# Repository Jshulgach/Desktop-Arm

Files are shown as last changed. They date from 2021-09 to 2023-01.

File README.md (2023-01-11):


# Desktop-Robotic-Arm
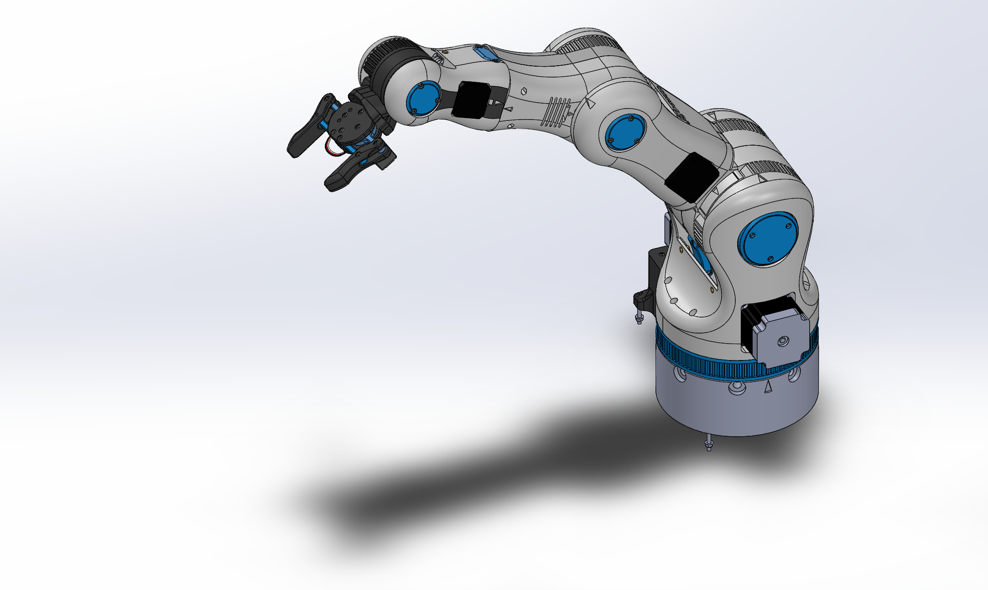
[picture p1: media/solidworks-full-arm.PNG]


The Desktop Robot Arm (better name TBD) is the complete package of a ROS2-based robot controller and the [Moveo](https://www.bcn3d.com/bcn3d-moveo-the-future-of-learning-robotic-arm/), a small-medium-sized fully 3D printable Open source 6 axis robotic arm. 

It is functionally and aesthetically similar to other amazing robot arms like the [KUKA KG Agilus](https://www.kuka.com/en-us/products/robotics-systems/industrial-robots/kr-agilus) or the [Fanuc LR Mate](https://www.fanucamerica.com/products/robots/series/lr-mate/lr-mate-200id) robotic arms in the robotics industry but is aimed for personal use, research, education and anyone interested in making their own robotic arm, at an affordable price! 

The main "selling points" of this arm that separate it from other existing DIY arms are:
+ Raspberry Pi 4 Model B - main processing unit for motion planning and listener routines
+ Arduino Mega microcontroller to interface with the robot systems
+ Runs on ROS2 (with Moveit2 for motion planning)
+ All 3D printable components (aside from nuts & bolts)
+ Less that $1,000 with the B.O.M
+ Capacity to integrate more features

# Where to start ? 
This Github repository contains Installation and Quick Start instructions for the Desktop Robot Arm project running ROS2 Humble off a Raspberry Pi 4, and contains folders for scripts, libraries, examples, and readme files. If you want to make the arm yourself, start with Hardware.

Table of Contents
---
+ [Hardware](#hardware)
+ [Raspberry PI 4 Installation](#rpi4-installation)
+ [Arduino Setup](#arduino-setup)
+ [Dance Demo](#demo)
+ [XBox Teleop](#xbox-teleop)
+ [Simulated Model](#simulated-model)
+ [Voice Control - Coming Soon!](#voice-control)
+ [Home Assistant Integration - Coming Soon!](#home-assistant-integration)
+ [HTC Vive Integration - coming Soon!](#htc-vive)
---

## Hardware:
<a name="hardware"/>

1. Building the arm
   + The full list of parts needed to assemble the arm can be found in the [B.O.M](tbd).

   + Instructables has a greate [step-by-step guide](https://www.instructables.com/Build-a-Giant-3D-Printed-Robot-Arm/) on 3D printing and assembling the arm pieces. 

2. Electrical wiring
   + A wiring diagram for the RAMPS 1.4 shield and Arduino Mega can be found in the [Electrical](tbd) folder.
   + A reference for the RAMPS 1.4 shield can be found on their [website](https://reprap.com/wiki/RAMPS_1.4) which shows the pin assignments. Please be sure to refer only to the 1.4 version of the shield.

---

## Raspberry Pi 4 Software Installation:
<a name="rpi4-installation"/>
These instructions were tested on Ubuntu 22.04.1 LTS running on a Raspberry Pi 4 64-bit 4Gb. If starting with a brand new Raspi and a blank microSD card, start with step 1 if you need to set up hardware.

1. Download the following software packages for flashing and writing to a new microSD card
   + [SD Memory Card Formatter](https://www.sdcard.org/downloads/formatter/)
   + [Raspberry Pi Imager](https://www.raspberrypi.com/software/)

2. Setting up Raspberry Pi 4
   + Follow the Imager instructions on writing the Ubuntu server image on Raspi 4. Please select Ubuntu 22.04 LTS. DO NOT install Ubuntu 22.10 LTS as the ROS2 humble debian packages aren't supported yet.
 
3. Install packages
   + Clone the Desktop Arm Github repository onto the specific `ros2_ws` folder which we create 
     ~~~
     mkdir -p ~/ros2_ws/src
     cd ~/ros2_ws/src
     git clone https://github.com/Jshulgach/Desktop-Arm.git
     ~~~

   + Run the `install.sh` bash script, which also includes installation steps for [ROS2 Humble](https://docs.ros.org/en/humble/Installation/Ubuntu-Development-Setup.html), [Moveit2](https://moveit.ros.org/install-moveit2/binary/), SSH, and other packages.
     ~~~
     cd Desktop-Arm
     chmod +x install.sh
     ./install.sh
     ~~~
4. DDNS Setup (Optional)
   + To allow access and remote control over the internet, we need to set up a Dynamic DNS. I've used the service [no-ip](https://www.noip.com) to create a free account and host a domain for the Raspberry Pi. [First create an account](https://www.noip.com/sign-up). More detailed instructions on setup are available on their [support page](https://www.noip.com/support/knowledgebase/installing-the-linux-dynamic-update-client-on-ubuntu/)
   + Download and install the no-ip software. You will be prompted to login with your No-IP account username and password. After logging into the DUC answer the questions to proceed. When asked how often you want the update to happen you can select the default number 30 (the interval is listed in minutes).
     ~~~
     mkdir ~/noip
     cd ~/noip
     wget https://www.noip.com/client/linux/noip-duc-linux.tar.gz
     tar vzxf noip-duc-linux.tar.gz
     cd noip-2.1.9-1
     sudo make
     sudo make install
     ~~~
   + Launch the client in the background and enable startup on boot
     ~~~
     sudo /usr/local/bin/noip2 -C
     systemctl enable noip2.service
     ~~~

## Arduino Setup:
<a name="arduino-setup"/>

An [Arduino Mega](https://diyi0t.com/arduino-mega-tutorial/) microcontroller is used to fit with the [RAMPS 1.4 Shield](https://reprap.org/wiki/RAMPS_1.4). Since the shield was designed to control a 3D printer or CNC machine with various stepper motor controllers and servos (along with limit switches and sensor readings), it was a great existing product to utilize. The primary microcontroller firmware needs to be [uploaded](https://docs.arduino.cc/software/ide-v2/tutorials/getting-started/ide-v2-uploading-a-sketch) onto the Arduino Mega, but it is RECOMMENDED to flash some of the test scripts first to make sure the arm works, like the dancing demo!

   + Add yourself to the dialout user group to enable usb serial communication. Replace USER with your username. You will need to log out and log in again for this change to take effect.
     ~~~
     sudo groupadd dialout
     sudo gpasswd -a USER dialout
     sudo usermod -a -G dialout USER
     sudo chmod a+rw /dev/ttyACM0
     ~~~
   + Once you're satisfied with testing, flash the 'desktop_arm_serial_control.ino' firmware (check for latest version) onto the microcontroller. I used the [Arduino IDE](https://www.arduino.cc/en/software) since it makes it easy to directly test and flash code.

At this point the robot should be good to go!
---

## Arduino Dance Demo
<a name="demo"/>

Flash the 'desktop-arm-dancing-demo.ino' script onto the Arduino and enable power to the arm. It should slowly run through random positions with the joints and verify that the system works.

--- 

## XBox Teleop Demo
<a name="xbox-teleop">

There are 2 versions with the Teleop control demo:

1. For manual joint control with an xbox controller, run the local teleop program by plugging in an xbox controller to the Raspberry Pi, then in a terminal run the launch command:
     ```
     ros2 launch desktop_arm teleop.launch.py
     ```

2. For remote control over the internet, the robot will run the same teleop program but with additional parameters:
   + Run the teleop program and start the remote control server
     ```
     ros2 launch desktop_arm teleop.launch.py start_server:=true manual:=false
     ```
   + On the client computer, connect the xbox controller and run the 'client-controller.py' python script.

---

Simulated Model 
<a name="simulated-model">
---
Coming Soon!

Voice Control
<a name="voice-control">
---
Coming Soon!

Home Assistant Integration
<a name="home-assistant-integration">
---
Coming Soon!

HTC Vive Integration
<a name="htc-vive">
---
Coming Soon!

---

# Support the project

This project is completely open source and free to all. Any help or advice is really appreciated. Thank you!

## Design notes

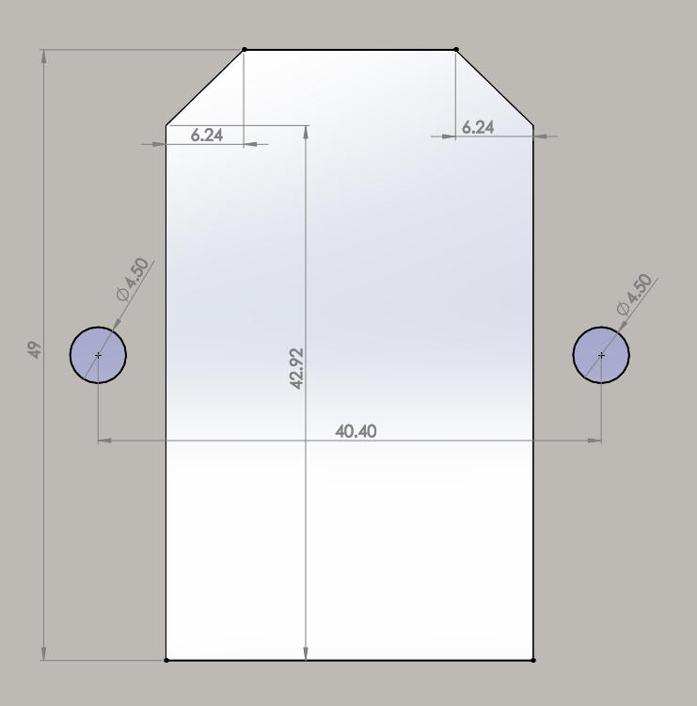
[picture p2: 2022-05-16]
CAD Models/ac-power-outlet-socket/AC Power Outlet Socket - laser cut.PNG

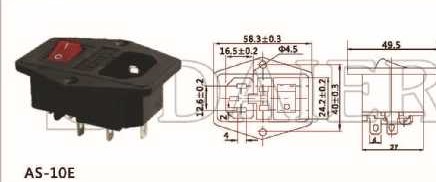
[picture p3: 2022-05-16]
CAD Models/ac-power-outlet-socket/AC Power Outlet Socket.jpg

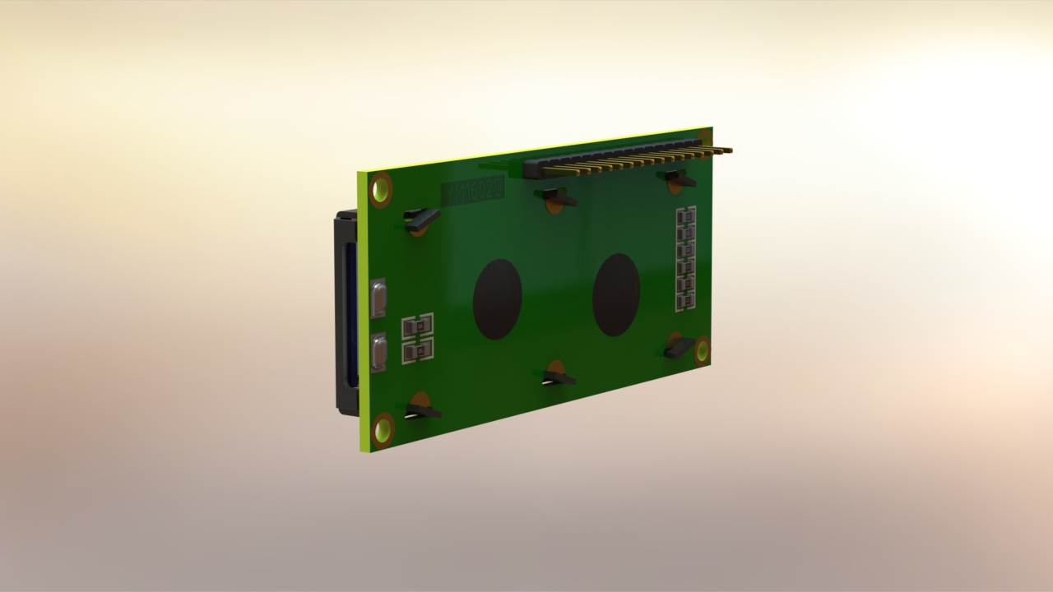
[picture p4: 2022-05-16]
CAD Models/16-x-2-lcd-display-module/lcd4.jpg

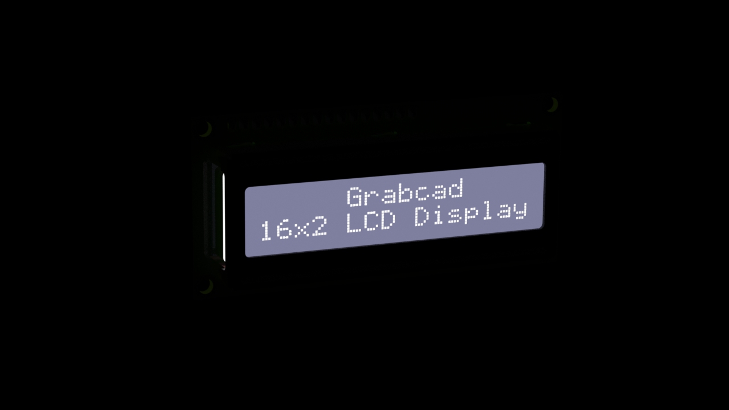
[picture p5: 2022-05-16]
CAD Models/16-x-2-lcd-display-module/lcd5.jpg

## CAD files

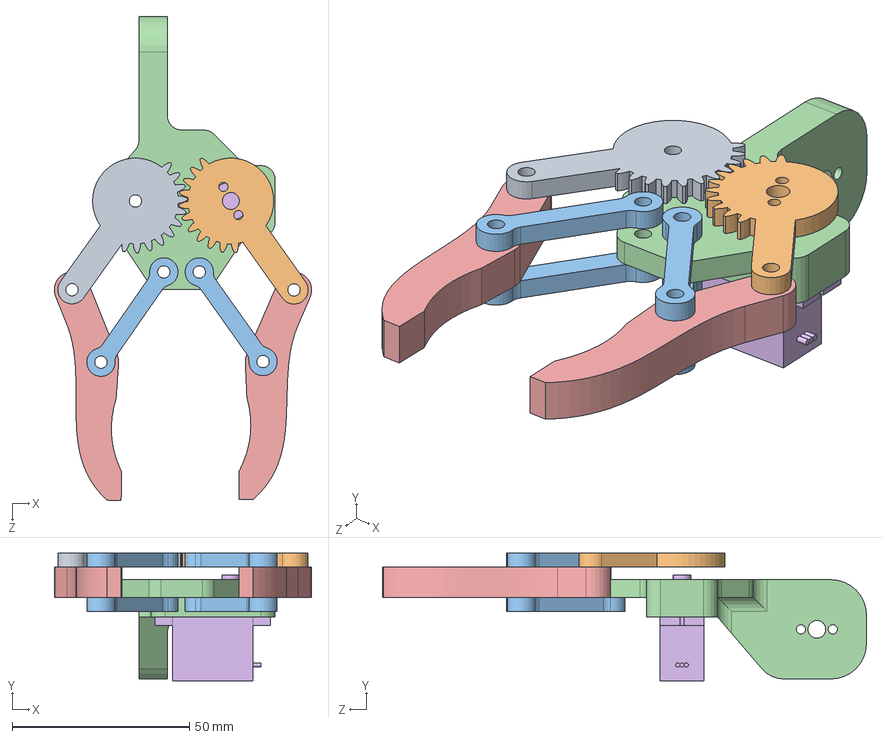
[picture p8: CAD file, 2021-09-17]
robot_resources/Arduino Robot Arm 3D Model/Gripper/Gripper Assembly.SLDASM
72.5 x 36.0 x 136.4 mm
gear1
gear2
grip link 1 x 4
Gripper base
Gripper 1 x 2
Servo Motor Micro 9g

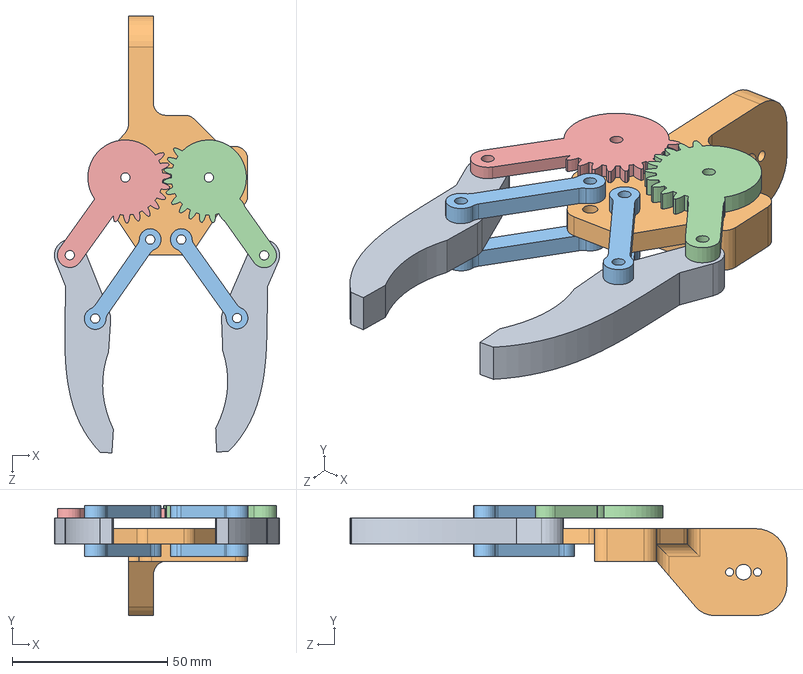
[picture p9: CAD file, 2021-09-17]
robot_resources/Arduino Robot Arm 3D Model/Gripper/Gripper Assembly_r1.SLDASM
72.5 x 35.5 x 140.7 mm
gear1_r1
gear2_r1
grip link 1_r1 x 4
Gripper base_r1
Gripper 1_r1 x 2

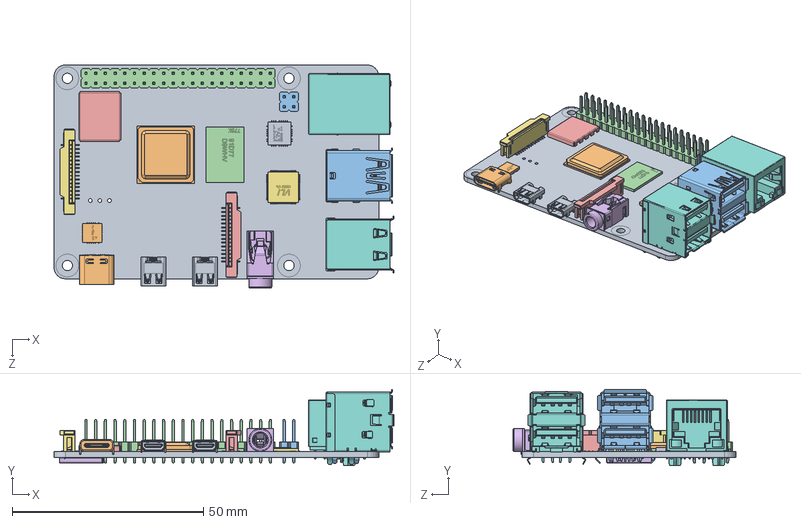
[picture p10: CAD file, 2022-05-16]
CAD Models/raspberry-pi-4-model-b/Raspberry Pi 4 Model B.SLDASM
89.0 x 19.9 x 58.4 mm
PCB, RPi4ModelB
Broadcom BCM2711B0 CPU, RPi4ModelB
2.54 mm DUPONT MALE PIN HEADER, POE, 2X2, RPi4ModelB
2.54 mm DUPONT MALE PIN HEADER, IO, 2X20, RPi4ModelB
Camera Connector, RPi4ModelB
Microphone Plug, RPi4ModelB
Display Connector, RPi4ModelB
Gigabit Ethernet Port, RPi4ModelB
Female Micro HDMI Connector, RPi4ModelB x 2
Female USB Type C Connector, RPi4ModelB
2X USB3.0 PORTS, RPi4ModelB
91D77 D9WHV 778K, 4 GB LPDDR4 SDRAM, RPi4ModelB
Cypress CYW43455 Wireless Module Cover, RPi4ModelB
SD Card Slot, RPi4ModelB
VIA VL805 PCIe USB 3.0 controller, RPi4ModelB
2X USB2.0 PORTS, RPi4ModelB
Broadcom BCM54213PE Gigabit Ethernet Transceiver, RPi4ModelB
MxL7704 Universal PMIC, RPi4ModelB

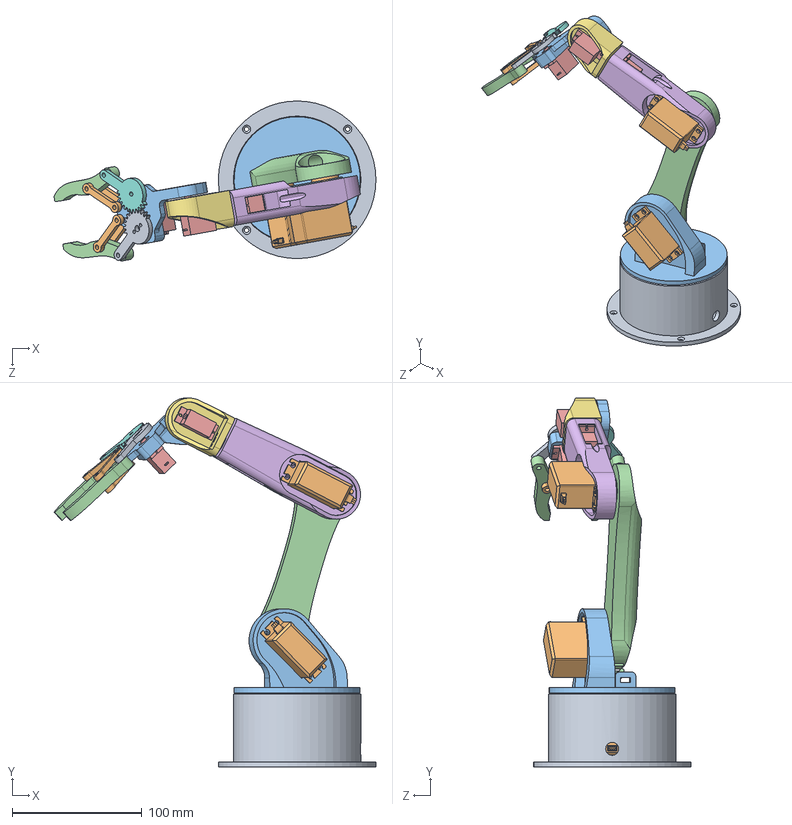
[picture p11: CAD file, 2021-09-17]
robot_resources/Arduino Robot Arm 3D Model/Robotic Arm.SLDASM
247.7 x 283.9 x 123.1 mm
Base
Servo Motor MG996R x 3
Waist
Arm 01
Servo Motor Micro 9g x 3
Arm 02 v3
Arm 03
gear1
gear2
grip link 1 x 4
Gripper base
Gripper 1 x 2

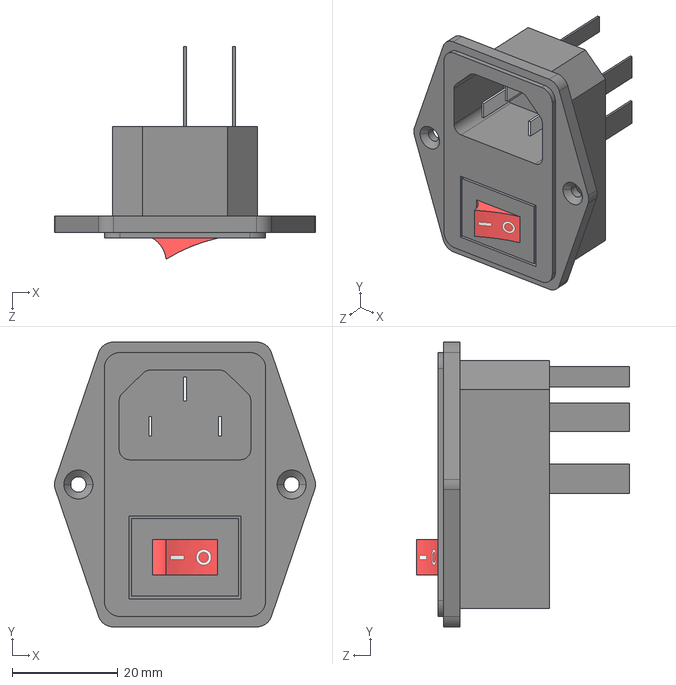
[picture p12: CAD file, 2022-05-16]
CAD Models/ac-power-outlet-socket/AC Input Connector and Switch.STEP
49.5 x 54.0 x 40.3 mm

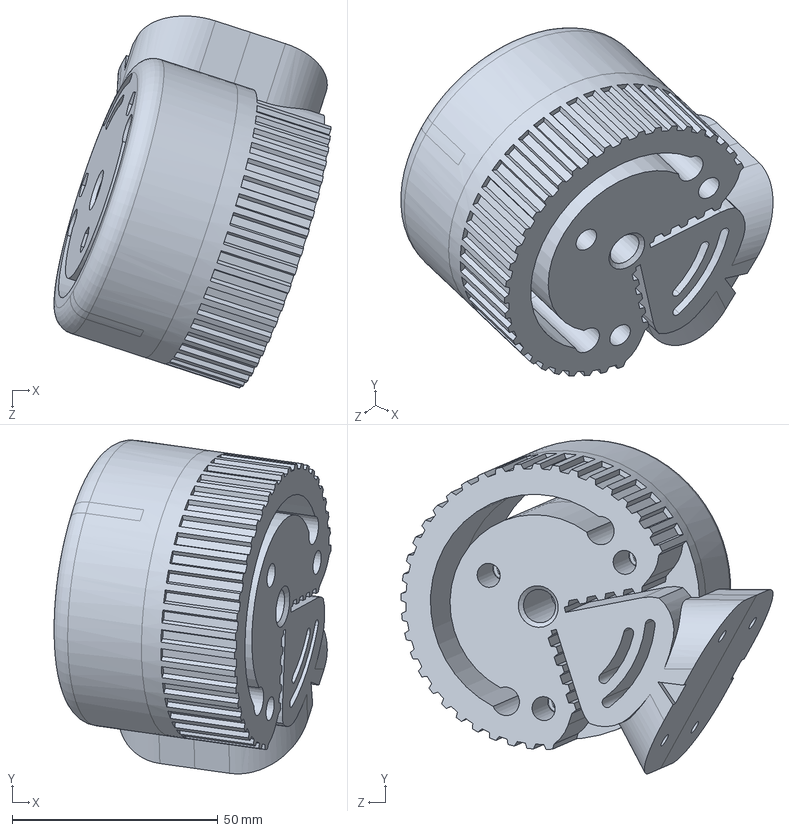
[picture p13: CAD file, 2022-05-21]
CAD Models/desktop_arm_link_5.SLDPRT
67.2 x 81.0 x 90.3 mm

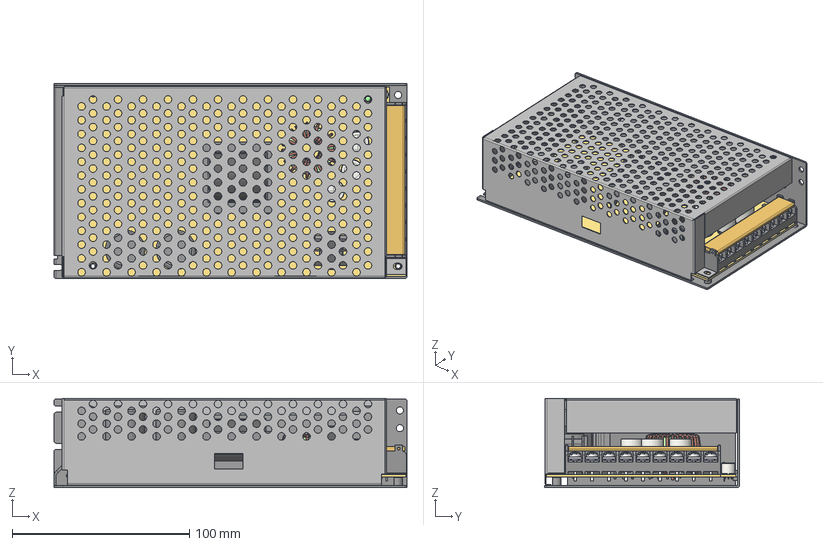
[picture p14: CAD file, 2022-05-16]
CAD Models/power-supply-s-240-12/PowerSupply_S-240-12.FCStd
199.0 x 110.0 x 50.3 mm
Case_Bottom
Case_Cover
PCB
LED_D3.0mm
C_Radial_D125mm_H200mm_P500mm_003
C_Radial_D125mm_H200mm_P500mm_001
C_Radial_D125mm_H200mm_P500mm_002
Potentiometer_Vertical
Elko_470uF_250V_001
Elko_470uF_250V_002

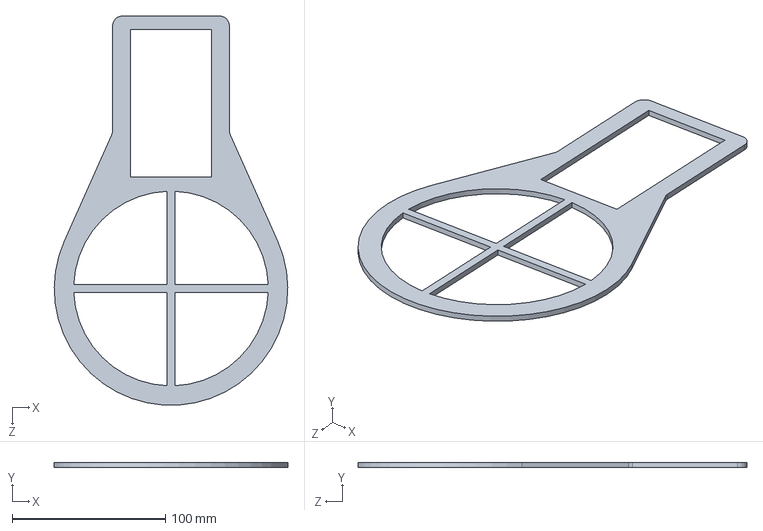
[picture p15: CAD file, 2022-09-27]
CAD Models/PSU Box/Rotating Base.SLDPRT
152.4 x 3.17 x 253.8 mm

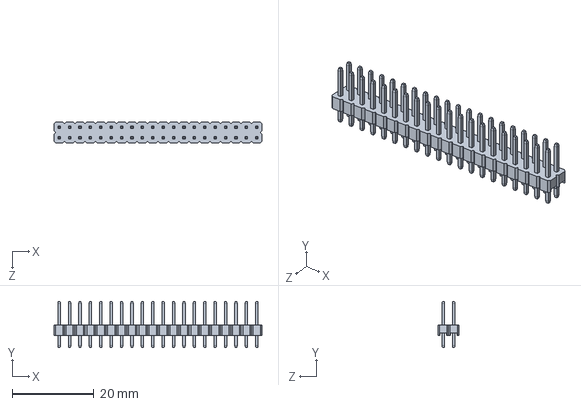
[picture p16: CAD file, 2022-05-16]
CAD Models/raspberry-pi-4-model-b/2.54 mm DUPONT MALE PIN HEADER, IO, 2X20, RPi4ModelB.SLDPRT
50.8 x 11.3 x 5.08 mm

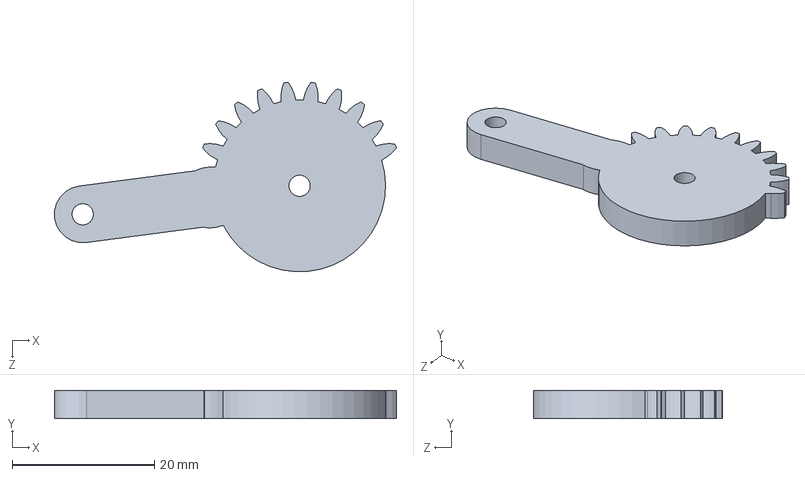
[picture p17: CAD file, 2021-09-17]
robot_resources/Arduino Robot Arm 3D Model/Gripper/gear2.SLDPRT
48.1 x 4.00 x 26.6 mm

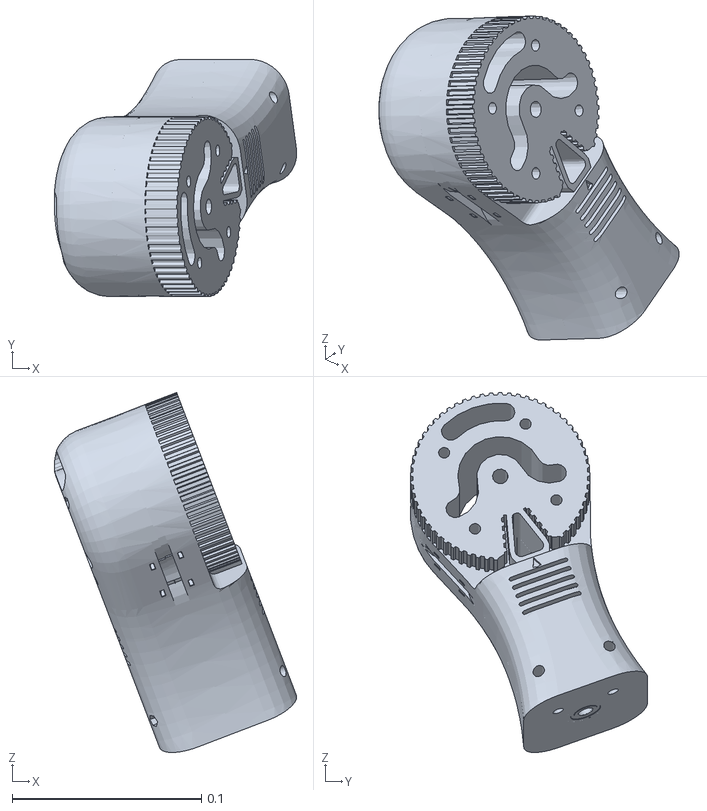
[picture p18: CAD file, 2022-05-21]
robot_resources/desktop_arm_description/meshes/link_3.STL
0.128 x 0.125 x 0.19

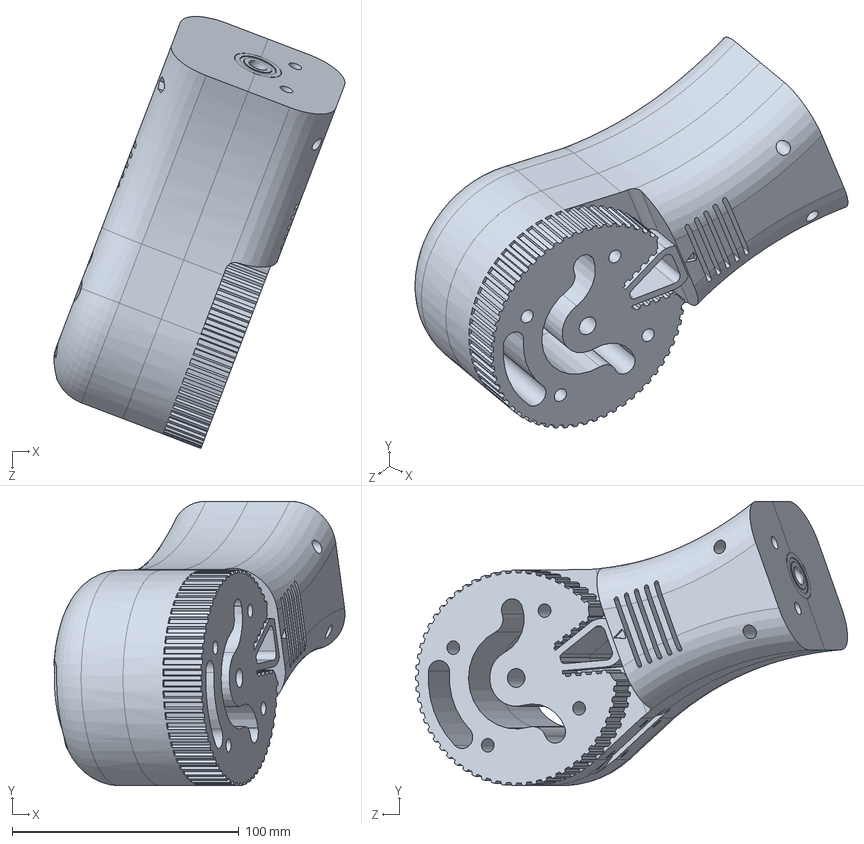
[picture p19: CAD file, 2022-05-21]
CAD Models/desktop_arm_link_3.SLDPRT
128.2 x 125.4 x 190.4 mm

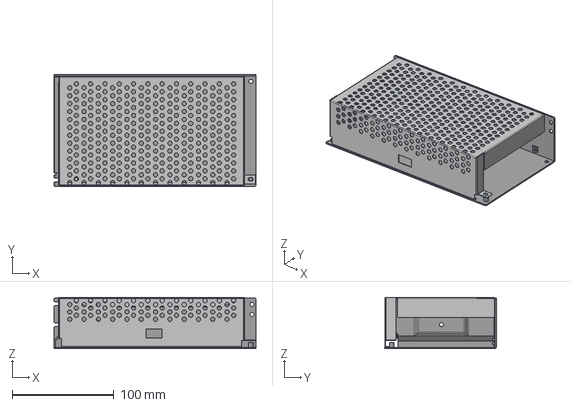
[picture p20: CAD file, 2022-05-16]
CAD Models/power-supply-s-240-12/Case.step
199.0 x 110.0 x 50.3 mm

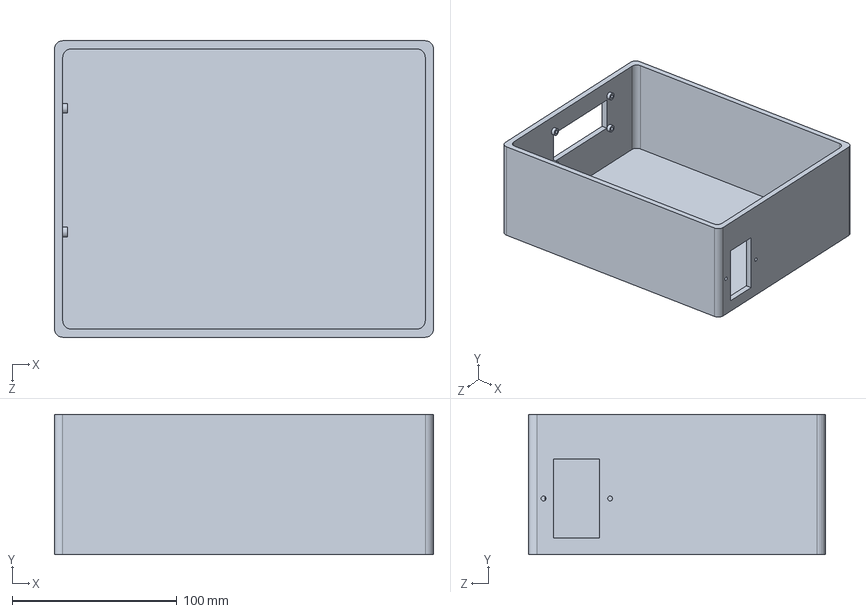
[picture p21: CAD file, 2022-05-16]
CAD Models/PSU Box/Bottom.SLDPRT
230.0 x 85.0 x 180.0 mm

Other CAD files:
CAD Models/raspberry-pi-4-model-b/Broadcom BCM54213PE Gigabit Ethernet Transceiver, RPi4ModelB.SLDPRT
robot_resources/Arduino Robot Arm 3D Model/Gripper/gear2_r1.SLDPRT
robot_resources/Arduino Robot Arm 3D Model/Servo Motor Micro 9g.SLDPRT
robot_resources/desktop_arm_description/meshes/link_5.STL
CAD Models/PSU Box/Bottom.STL
CAD Models/PSU Box/Raspi Shelf.SLDPRT
CAD Models/PSU Box/Rotating Base.STL
CAD Models/ac-power-outlet-socket/AC Input Connector and Switch.x_t
CAD Models/desktop_arm_base.SLDPRT
CAD Models/power-supply-s-240-12/src_Case.FCStd
CAD Models/raspberry-pi-4-model-b/2.54 mm DUPONT MALE PIN HEADER, IO, 2X40, RPi4ModelB.SLDPRT
CAD Models/raspberry-pi-4-model-b/2.54 mm DUPONT MALE PIN HEADER, POE, 2X2, RPi4ModelB.SLDPRT
CAD Models/raspberry-pi-4-model-b/2X USB2.0 PORTS, RPi4ModelB.SLDPRT
CAD Models/raspberry-pi-4-model-b/2X USB3.0 PORTS, RPi4ModelB.SLDPRT
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

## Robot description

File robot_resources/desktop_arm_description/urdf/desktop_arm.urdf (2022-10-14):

<?xml version="1.0" encoding="utf-8"?>
<!-- This URDF was automatically created by SolidWorks to URDF Exporter! Originally created by Stephen Brawner (brawner@gmail.com) 
     Commit Version: 1.6.0-4-g7f85cfe  Build Version: 1.6.7995.38578
     For more information, please see http://wiki.ros.org/sw_urdf_exporter -->
<robot name="desktop-arm" xmlns:xacro="http://ros.org/wiki/xacro">
  <link name="base_link">
    <inertial>
      <origin xyz="0 0 0" rpy="0 0 0" />
      <mass value="0.64235" />
      <inertia ixx="0.0015157" ixy="-2.584E-07" ixz="-1.4498E-07" iyy="0.0015152" iyz="6.003E-08" izz="0.002624" />
    </inertial>
    <visual>
      <origin xyz="0 0 0" rpy="0 0 0" />
      <geometry>
        <mesh filename="package://desktop_arm_description/meshes/base_link.STL" />
      </geometry>
      <material name="">
        <color rgba="0.79216 0.81961 0.93333 1" />
      </material>
    </visual>
    <collision>
      <origin xyz="0 0 0" rpy="0 0 0" />
      <geometry>
        <mesh filename="package://desktop_arm_description/meshes/base_link.STL" />
      </geometry>
    </collision>
  </link>
  <link name="link_1">
    <inertial>
      <origin xyz="1.32150942671883E-05 0.0840712343150202 -0.000226674153144618" rpy="0 0 0" />
      <mass value="2.06098242470071" />
      <inertia ixx="0.00723151267076472" ixy="8.50060421303669E-08" ixz="-0.000493369007400085" iyy="0.00643124857029598" iyz="8.77055790859003E-07" izz="0.00833376606191396" />
    </inertial>
    <visual>
      <origin xyz="0 0 0" rpy="0 0 0" />
      <geometry>
        <mesh filename="package://desktop_arm_description/meshes/link_1.STL" />
      </geometry>
      <material name="">
        <color rgba="0.792156862745098 0.819607843137255 0.933333333333333 1" />
      </material>
    </visual>
    <collision>
      <origin xyz="0 0 0" rpy="0 0 0" />
      <geometry>
        <mesh filename="package://desktop_arm_description/meshes/link_1.STL" />
      </geometry>
    </collision>
  </link>
  <joint name="joint_1" type="revolute">
    <origin xyz="0.0320497775774861 -0.156148136610897 0.0881843828733705" rpy="1.5707963267949 0 0.70838946909971" />
    <parent link="base_link" />
    <child link="link_1" />
    <axis xyz="0 1 0" />
    <limit lower="-1.3" upper="1.3" effort="0" velocity="0" />
  </joint>
  <link name="link_2">
    <inertial>
      <origin xyz="0.01789 0.058654 -0.05071" rpy="0 0 0" />
      <mass value="1.9263" />
      <inertia ixx="0.0047439" ixy="-0.00037569" ixz="0.00028127" iyy="0.0038445" iyz="0.00096517" izz="0.0041374" />
    </inertial>
    <visual>
      <origin xyz="0 0 0" rpy="0 0 0" />
      <geometry>
        <mesh filename="package://desktop_arm_description/meshes/link_2.STL" />
      </geometry>
      <material name="">
        <color rgba="0.79216 0.81961 0.93333 1" />
      </material>
    </visual>
    <collision>
      <origin xyz="0 0 0" rpy="0 0 0" />
      <geometry>
        <mesh filename="package://desktop_arm_description/meshes/link_2.STL" />
      </geometry>
    </collision>
  </link>
  <joint name="joint_2" type="revolute">
    <origin xyz="0 0.1655 0" rpy="0.288567690879059 -0.0158462661982318 0.10895820907763" />
    <parent link="link_1" />
    <child link="link_2" />
    <axis xyz="0.934125217802764 0 0.356945482482884" />
    <limit lower="-1.3" upper="1.3" effort="0" velocity="0" />
  </joint>
  <link name="link_3">
    <inertial>
      <origin xyz="0.0139481789637224 0.0146668632687502 -0.0359246194913087" rpy="0 0 0" />
      <mass value="0.725230105179457" />
      <inertia ixx="0.00179957485676987" ixy="-0.000147553492540297" ixz="0.000456755493645833" iyy="0.00154110709734523" iyz="0.00038828009924826" izz="0.000772747821956818" />
    </inertial>
    <visual>
      <origin xyz="0 0 0" rpy="0 0 0" />
      <geometry>
        <mesh filename="package://desktop_arm_description/meshes/link_3.STL" />
      </geometry>
      <material name="">
        <color rgba="0.792156862745098 0.819607843137255 0.933333333333333 1" />
      </material>
    </visual>
    <collision>
      <origin xyz="0 0 0" rpy="0 0 0" />
      <geometry>
        <mesh filename="package://desktop_arm_description/meshes/link_3.STL" />
      </geometry>
    </collision>
  </link>
  <joint name="joint_3" type="revolute">
    <origin xyz="0.0533123755144546 0.163058763880744 -0.139518320956508" rpy="-0.28856769087906 -0.0158462661982266 -0.10895820907763" />
    <parent link="link_2" />
    <child link="link_3" />
    <axis xyz="0.934125217802763 0 0.356945482482886" />
    <limit lower="-1.3" upper="1.3" effort="0" velocity="0" />
  </joint>
  <link name="link_4">
    <inertial>
      <origin xyz="0.0184305955320793 0.0223219439403024 -0.0554419139160314" rpy="0 0 0" />
      <mass value="0.332133737054409" />
      <inertia ixx="0.000492451112757706" ixy="-2.8044250164716E-05" ixz="6.1771366365912E-05" iyy="0.000556523835973434" iyz="0.000103934198616861" izz="0.00036921676282899" />
    </inertial>
    <visual>
      <origin xyz="0 0 0" rpy="0 0 0" />
      <geometry>
        <mesh filename="package://desktop_arm_description/meshes/link_4.STL" />
      </geometry>
      <material name="">
        <color rgba="0.792156862745098 0.819607843137255 0.933333333333333 1" />
      </material>
    </visual>
    <collision>
      <origin xyz="0 0 0" rpy="0 0 0" />
      <geometry>
        <mesh filename="package://desktop_arm_description/meshes/link_4.STL" />
      </geometry>
    </collision>
  </link>
  <joint name="joint_4" type="revolute">
    <origin xyz="0.039132 0.040964 -0.10092" rpy="-0.81888 0.68462 3.0043" />
    <parent link="link_3" />
    <child link="link_4" />
    <axis xyz="0.33384 0.35396 -0.87365" />
    <limit lower="-1.3" upper="1.3" effort="0" velocity="0" />
  </joint>
  <link name="link_5">
    <inertial>
      <origin xyz="0.0003711 -0.0019484 -0.0032986" rpy="0 0 0" />
      <mass value="0.15863" />
      <inertia ixx="0.0001012" ixy="-3.4148E-06" ixz="1.3247E-05" iyy="6.4478E-05" iyz="-7.7884E-06" izz="6.1328E-05" />
    </inertial>
    <visual>
      <origin xyz="0 0 0" rpy="0 0 0" />
      <geometry>
        <mesh filename="package://desktop_arm_description/meshes/link_5.STL" />
      </geometry>
      <material name="">
        <color rgba="0.79216 0.81961 0.93333 1" />
      </material>
    </visual>
    <collision>
      <origin xyz="0 0 0" rpy="0 0 0" />
      <geometry>
        <mesh filename="package://desktop_arm_description/meshes/link_5.STL" />
      </geometry>
    </collision>
  </link>
  <joint name="joint_5" type="revolute">
    <origin xyz="0.035644 0.037793 -0.09328" rpy="0.99317 -0.27115 0.21303" />
    <parent link="link_4" />
    <child link="link_5" />
    <axis xyz="0.9426 -0.13293 0.30633" />
    <limit lower="-1.3" upper="1.3" effort="0" velocity="0" />
  </joint>
  <link name="end_effector">
    <inertial>
      <origin xyz="0.14241 0.38652 -0.15071" rpy="0 0 0" />
      <mass value="0.069485" />
      <inertia ixx="1.6525E-05" ixy="2.5479E-06" ixz="-8.6292E-07" iyy="2.184E-05" iyz="-5.1516E-06" izz="1.5862E-05" />
    </inertial>
    <visual>
      <origin xyz="0 0 0" rpy="0 0 0" />
      <geometry>
        <mesh filename="package://desktop_arm_description/meshes/end_effector.STL" />
      </geometry>
      <material name="">
        <color rgba="0.79216 0.81961 0.93333 1" />
      </material>
    </visual>
    <collision>
      <origin xyz="0 0 0" rpy="0 0 0" />
      <geometry>
        <mesh filename="package://desktop_arm_description/meshes/end_effector.STL" />
      </geometry>
    </collision>
  </link>
  <joint name="joint_6" type="fixed">
    <origin xyz="0.17605 0.29813 -0.29218" rpy="1.1615 0.33095 -2.9233" />
    <parent link="link_5" />
    <child link="end_effector" />
    <axis xyz="0 0 0" />
  </joint>
</robot>

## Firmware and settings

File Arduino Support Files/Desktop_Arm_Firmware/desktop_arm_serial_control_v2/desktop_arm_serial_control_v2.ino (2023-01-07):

 /* (c) Jonathan Shulgach - Cite and Notice license:
   All modifications to this code or use of it must include this notice and give credit for use.

   Credit requirements:
    All publications using this code must cite all contributors to this code.
    A list must be updated below indicating the contributors alongside the original or modified code appropriately.
    All code built on this code must retain this notice. All projects incorporating this code must retain this license text alongside the original or modified code.
    All projects incorporating this code must retain the existing citation and license text in each code file and modify it to include all contributors.
    Web, video, or other presentation materials must give credit for the contributors to this code, if it contributes to the subject presented.
    All modifications to this code or other associated documentation must retain this notice or a modified version which may only involve updating the contributor list.

    Primary Authors:
      - Jonathan Shulgach, PhD Student - Neuromechatronics Lab, Carnegie Mellon University

   Contributor List:
   
   Other than the above, this code may be used for any purpose and no financial or other compensation is required.
   Contributors do not relinquish their copyright(s) to this software by virtue of offering this license.
   Any modifications to the license require permission of the authors.

   Description:
      This Arduino code controls the Desktop Arm robot. it uses microstepping of steppermotors for precise joint states,
      serial parsing for command inputs and outputs, an optional PID controller for joint state handling, text output on an LCD
      display using the SerLCD module, servo control, 
     
      - More info on Qwiic here: https://www.sparkfun.com/qwiic
      - Click here to get the library: http://librarymanager/All#SparkFun_SerLCD
      - see Serial Input Basics by Robin2: https://forum.arduino.cc/t/serial-input-basics-updated/382007/2
      - AVR-Based Serial Enabled LCDs Hookup Guide
        https://learn.sparkfun.com/tutorials/avr-based-serial-enabled-lcds-hookup-guide
      - Reference for awesome multi-stepper serial command parsing from JustinJKwok's Github
        https://github.com/JustinJKwok/Arduino-multi-stepper/blob/master/multi_stepper.ino

*/
#include <Servo.h>
//#include <PID_v1.h>
#include <Wire.h>
#include <SerLCD.h> //Click here to get the library: http://librarymanager/All#SparkFun_SerLCD
#include <AccelStepper.h>
//#include <ezButton.h>
//#include <TMC2208Stepper.h>
//#include <TMC2208Stepper_REGDEFS.h>
#include "Configuration.h"
#include "pins.h"

// Stepper Motors (Up to 10 steppers can be handled as a group by AccelStepper)
const int numSteppers = 5;
AccelStepper joint0Stepper = AccelStepper(motorInterfaceType, JOINT0_STEP_PIN, JOINT0_DIR_PIN);  // Rotating base joint
AccelStepper joint1Stepper = AccelStepper(motorInterfaceType, JOINT1_STEP_PIN, JOINT1_DIR_PIN);  // Joint 1 (shoulder rotation)
AccelStepper joint2Stepper = AccelStepper(motorInterfaceType, JOINT2_STEP_PIN, JOINT2_DIR_PIN);  // Joint 2 ( elbow rotation)
AccelStepper joint3Stepper = AccelStepper(motorInterfaceType, JOINT3_STEP_PIN, JOINT3_DIR_PIN);  // Joint 3 (rotating wrist joint)
AccelStepper joint4Stepper = AccelStepper(motorInterfaceType, JOINT4_STEP_PIN, JOINT4_DIR_PIN);  // Joint 4 (moves the gripper)
AccelStepper* steppers[numSteppers] = {&joint0Stepper, &joint1Stepper, &joint2Stepper, &joint3Stepper, &joint4Stepper};

// PID controllers
//double Setpoint0, Setpoint1, Setpoint2, Setpoint3, Setpoint4;
//float setpointPos[] = {&Setpoint0, &Setpoint1, &Setpoint2, &Setpoint3, &Setpoint4};
//double Input0, Input1, Input2, Input3, Input4;
//float inputPos[] = {&Input0, &Input1, &Input2, &Input3, &Input4};
//double Output0, Output1, Output2, Output3, Output4;
//float outputPos[] = {&Output0, &Output1, &Output2, &Output3, &Output4};
//PID joint0PID(&Input0, &Output0, &Setpoint0, Kp, Ki, Kd, DIRECT);
//PID joint1PID(&Input1, &Output1, &Setpoint1, Kp, Ki, Kd, DIRECT);
//PID joint2PID(&Input2, &Output2, &Setpoint2, Kp, Ki, Kd, DIRECT);
//PID joint3PID(&Input3, &Output3, &Setpoint3, Kp, Ki, Kd, DIRECT);
//PID joint4PID(&Input4, &Output4, &Setpoint4, Kp, Ki, Kd, DIRECT);
//PID* stepperPID[numSteppers] = {&joint0PID, &joint1PID, &joint2PID, &joint3PID, &joint4PID};

// Servos
Servo gripper;

//ezButton joint0Switch(JOINT0_MIN_PIN);  // create ezButton object that attach to pin 7;
//ezButton joint1Switch(JOINT1_MIN_PIN);  // create ezButton object that attach to pin 7;
//ezButton joint2Switch(JOINT2_MIN_PIN);  // create ezButton object that attach to pin 7;
//ezButton joint3Switch(JOINT3_MIN_PIN);  // create ezButton object that attach to pin 7;
//ezButton joint4Switch(JOINT4_MIN_PIN);  // create ezButton object that attach to pin 7;

SerLCD lcd; // Initialize the library with default I2C address 0x72

//Custom Characters
byte selectChar[] = {
  B00000,
  B00000,
  B00110,
  B01111,
  B01111,
  B00110,
  B00000,
  B00000
};

// Stepper motor and servo specific variables including limit switches
int homeSwitchPin[] = {JOINT0_MIN_PIN, JOINT1_MIN_PIN, JOINT2_MIN_PIN, JOINT3_MIN_PIN, JOINT4_MIN_PIN};
int jointEnablePin[] = {JOINT0_ENABLE_PIN, JOINT1_ENABLE_PIN, JOINT2_ENABLE_PIN, JOINT3_ENABLE_PIN, JOINT4_ENABLE_PIN};
float minPosition[] = {JOINT0_MIN_POS, JOINT1_MIN_POS, JOINT2_MIN_POS, JOINT3_MIN_POS, JOINT4_MIN_POS};
float maxPosition[] = {JOINT0_MAX_POS, JOINT1_MAX_POS, JOINT2_MAX_POS, JOINT3_MAX_POS, JOINT4_MAX_POS};
float maxMotorSpeed[] = {JOINT0_MAX_SPEED, JOINT1_MAX_SPEED, JOINT2_MAX_SPEED, JOINT3_MAX_SPEED, JOINT4_MAX_SPEED};
float maxMotorAcceleration[] = {JOINT0_MAX_ACCELERATION, JOINT1_MAX_ACCELERATION, JOINT2_MAX_ACCELERATION, JOINT3_MAX_ACCELERATION, JOINT4_MAX_ACCELERATION};
float homingBuffer[] = {JOINT0_HOMING_BUFFER, JOINT1_HOMING_BUFFER, JOINT2_HOMING_BUFFER, JOINT3_HOMING_BUFFER, JOINT4_HOMING_BUFFER}; 
float stepsPerRev[] = {JOINT0_REV_STEPS, JOINT1_REV_STEPS, JOINT2_REV_STEPS, JOINT3_REV_STEPS, JOINT4_REV_STEPS}; 
bool isDisabled[] = {JOINT0_DISABLED, JOINT1_DISABLED, JOINT2_DISABLED, JOINT3_DISABLED, JOINT4_DISABLED};
float stepperPos[numSteppers] = {0.0,0.0,0.0,0.0,0.0};

// Global state-tracking variables
//int n_repeat, t_start, x;
bool hasHomed[] = {false, false, false, false, false};
bool isHoming[] = {false, false, false, false, false};
bool hasReported[] = {true, true, true, true, true};
int gripper_state;

// Serial communication handling for commands 
bool VERBOSE = false;
char *DELIMITER = " ";
char endChar = '\n';
const int MAXCHARS = 32;
const int MAXTOKENS = 5;
char incomingChars[MAXCHARS];
char incomingParams[MAXTOKENS][MAXCHARS]; //incoming chars parsed into cstrings
char tempChars[MAXCHARS];
bool newSerialData = false;
int numTokens = 0;


void setup()
{
  // ==== Serial Setup ====
  Serial.begin(BAUDRATE);
  Serial.println("Ready");
  
  // ===== Initialize stepper motors  and servos =====
  setupPins();
  //setupSwitches(1);
  setupJoints();
  setupServos();
  
  // === Select one or the other for zero positioning ===
  //homeJoints();
  //zeroJoints();
  setCurrentPosToMid();
  //setCurrentPosToZero();
  //send_home_state();
  delay(100);
  whereMotor();
 
  // ===== LCD Setup =====
  setupLCD();
    
  //t_start = millis();  

}

void loop(){ 

    checkConnection(); // Indicate if connected via USB
    readNextSerial(); // Check serial input stream if any data is available
    if (newSerialData == true)
    {
        if (VERBOSE)
        { 
            Serial.print("Received: ");
            Serial.println(incomingChars);
        }
        strcpy(tempChars, incomingChars);
        parseTokens(); // Breaks up and evaluates incoming string message
        parseCommand(); // Handles parsed command snd underlying subtasks
    }

    updateJoints(); // Check the state of the robot
    //updateLCD(); // Update the front display

    // anything else...

    newSerialData = false; //reset new data flag
    for (int i = 0; i < numTokens; ++i) //reset the parsed tokens
    {
        incomingParams[i][0] = '\0';
    }
    numTokens = 0; //reset the token counter
}

void checkConnection()
{
  if (Serial) {
    digitalWrite(CONNECT_LED_PIN_OUT, HIGH);
  } else {
    digitalWrite(CONNECT_LED_PIN_OUT, LOW);
  }
}

void readNextSerial()
{
    //read serial buffer until newline, read into incomingChars
    static int ndx = 0;
    char nextChar;
    while (Serial.available() > 0 && newSerialData == false)
    {
        nextChar = Serial.read();
        //keep adding into cstring until newline
        if (nextChar != endChar) 
        {
            incomingChars[ndx] = nextChar;
            ++ndx;
            if (ndx >= MAXCHARS) 
            {
                ndx = MAXCHARS - 1;
            }
        } 
        else 
        {
            //if reading newline then terminate cstring and indicate there is new data to process
            incomingChars[ndx] = '\0';
            ndx = 0;
            newSerialData = true;
        }
    }
}

void parseTokens()
{
    char* token;
    numTokens = 0;

    token = strtok(tempChars, DELIMITER);

    while (token != NULL)
    {
        //save into cstring array and read next portion
        strcpy(incomingParams[numTokens], token);
        ++numTokens;

        if (numTokens >= MAXTOKENS)
        {
            numTokens = MAXTOKENS - 1;
        }
        token = strtok(NULL, DELIMITER);
    }
}

void parseCommand()
{
    //(For some reason using the switch command broke for me, later learned cannot 
    // use switch/case for cstring comparisons, actually better with if-else
    if (strcmp(incomingParams[0], "enablemotor") == 0)
    {
        enableMotor();
    } 
    else if (strcmp(incomingParams[0], "disablemotor") == 0)
    {
        disableMotor();
    } 
    else if (strcmp(incomingParams[0], "motorinfo") == 0)
    {
        whereMotor();
    }
    else if (strcmp(incomingParams[0], "gripperinfo") == 0)
    {
        printGripperInfo();
    }
    else if (strcmp(incomingParams[0], "robotinfo") == 0)
    {
      printRobotInfoCmd();
    }
    else if (strcmp(incomingParams[0], "movemotor") == 0)
    {
        moveMotor();
    }
    else if (strcmp(incomingParams[0], "gripper") == 0)
    {
        parse_gripper_command();
    }
    else if (strcmp(incomingParams[0], "help")==0)
    {
        printHelp(); // Cool help command
    }
    else if (strcmp(incomingParams[0], "debugon") == 0)
    {
        setDebugOn();
    }
    else if (strcmp(incomingParams[0], "debugoff") == 0)
    {
        setDebugOff();
    }
    else if (strcmp(incomingParams[0], "enablefan") == 0)
    {
        enableFan();
    }
    else if (strcmp(incomingParams[0], "disablefan") == 0)
    {
        disableFan();
    }
    else if (strcmp(incomingParams[0], "setmotorspeed") == 0)
    {
        setMotorSpeed();
    }
    else if (strcmp(incomingParams[0], "setmotoracceleration") == 0)
    {
        setMotorAcceleration();
    }
    else
    {
        //no command exists
        Serial.print("No command \"");
        Serial.print(incomingParams[0]);
        Serial.println("\" exists. Type \"help\' for more info.");
    }  
}

void updateJoints()
{
    //run stepper motors
    for (int i = 0; i < numSteppers; ++i)
    {
        // if currently homing and the limit switch is depressed
        if (isHoming[i] && !digitalRead(homeSwitchPin[i]))
        {
            steppers[i]->enableOutputs();
            steppers[i]->move(homingBuffer[i] * stepsPerRev[i]);
            hasReported[i] = false;   
        }
        if (steppers[i]->distanceToGo() != 0)
        {
            // can this cause intervals to skip? because not EXACTLY a multiple of 100 on evaluation
            // might depend on how slow/fast the main loop is, if too fast then it will repeat, if to slow it may skip
            // not too critical since only used for printing 
            if (millis() % 200 == 0 && VERBOSE)
            {
                Serial.print("Moving, distance to go for stepper ");
                Serial.print(i+1);
                Serial.print(" is: ");
                Serial.print(steppers[i]->distanceToGo()*360/stepsPerRev[i]);
                Serial.print(" at ");
                Serial.println(convertStepperPosToDeg(i, steppers[i]->currentPosition()));
            }
            //if (USE_PID) stepperPID[i]->Compute();
            steppers[i]->run();
            stepperPos[i] = steppers[i]->currentPosition()*360 / stepsPerRev[i];
        }
    }
}

void moveMotor()
{
  //Check the number of tokens
    if (numTokens != 3)
    {
        Serial.println("Invalid number of parameters");
        return;
    }

    //Check that the first number is an integer and is within the range of valid stepper numbers
    long motorNum;
    if (!isValidMotorNum(incomingParams[1], motorNum))
    {
        return;
    }
    
    //Check that the second number is an actual number and is within the range of valid positons
    double targetPos;
    if (!isValidTargetPos(incomingParams[2], motorNum, targetPos))
    {
        return;
    }

    // Check limit switch
    //if (!hasHomed[motorNum-1])
    //{
    //    Serial.print("You must home stepper ");
    //    Serial.print(motorNum);
    //    Serial.println(" before you can move it");
    //    return;
    //}
    if (isDisabled[motorNum-1])
    {
      Serial.print("Motor ");
      Serial.print(motorNum-1);
      Serial.println(" disabled");
      return;
    }
    int new_pos = convertDegToStepperPos(motorNum-1, targetPos);
    if (VERBOSE)
    {
        Serial.print("New joint value position received: ");
        Serial.println(new_pos);
    }
    //if (USE_PID)
    //{
    //    setpointPos[motorNum-1] = targetPos;
    //    updateMotorPosPID(motorNum-1, targetPos);
    //}
    steppers[motorNum-1]->enableOutputs();
    steppers[motorNum-1]->moveTo(new_pos);
    hasReported[motorNum-1] = false;
     
}

int convertDegToStepperPos(int motorNum, int targetPos)
{
  float midpos = float( (maxPosition[motorNum] + minPosition[motorNum])/2 );
  int new_pos = int( (midpos + targetPos*stepsPerRev[motorNum]/360) );
  return new_pos;
}

int convertStepperPosToDeg(int motorNum, int targetPos)
{
  float midpos = float( (maxPosition[motorNum] + minPosition[motorNum])/2 );
  //Serial.print("mid position: ");
  //Serial.println(midpos);
  int new_pos = int( (targetPos - midpos)*360/stepsPerRev[motorNum] );
  return new_pos;
}

void enableMotor()
{
    if (numTokens == 1)
    {
        for (int i=0; i<numSteppers; i++)
        {
            steppers[i]->stop();
            steppers[i]->enableOutputs();
        }
        if (VERBOSE)
        {
            Serial.println("Stepper motors have been enabled");
        }
    }
    if (numTokens == 2)
    {
        long motorNum;
        if (!isValidMotorNum(incomingParams[1], motorNum))
        {
            return;
        }
        steppers[motorNum-1]->stop();
        steppers[motorNum-1]->enableOutputs();
        if (VERBOSE)
        {
            Serial.print("Stepper ");
            Serial.print(motorNum);
            Serial.println(" has been enabled");
        }
    }
    else
    {
        Serial.println("Invalid number of parameters");
    }    
}

void enableFan()
{
    digitalWrite(FAN_0_PIN, HIGH);  
}

void disableFan()
{
    digitalWrite(FAN_0_PIN, LOW);  
}

void disableMotor()
{
    if (numTokens == 1)
    {
        for (int i = 0; i < numSteppers; ++i)
        {
            steppers[i]->stop();
            steppers[i]->disableOutputs();
        }
        if (VERBOSE)
        {
            Serial.println(F("Steppers have been disabled"));
        }
    }
    else if (numTokens == 2)
    {
        long motorNum;
        if (!isValidMotorNum(incomingParams[1], motorNum))
        {
            return;
        }
        steppers[motorNum-1]->stop();
        steppers[motorNum-1]->disableOutputs();
        if (VERBOSE)
        {
            Serial.print("Stepper ");
            Serial.print(motorNum);
            Serial.println(" has been disabled");
        }
    }
    else
    {
        Serial.println("Invalid number of parameters");
    }
}

void whereMotor()
{
    if (numTokens == 0 || numTokens == 1)
    {
        for (int i = 0; i < numSteppers; ++i)
        {
            Serial.print("Stepper ");
            Serial.print(i+1);
            Serial.print(" is at = ");
            Serial.print(convertStepperPosToDeg(i, steppers[i]->currentPosition()));
            Serial.print(" deg [");
            Serial.print(steppers[i]->currentPosition());
            Serial.println(" steps]");
        }
    }
    else if (numTokens == 2)
    {
        long motorNum;
        if (!isValidMotorNum(incomingParams[1], motorNum))
        {
            return;
        }
        Serial.print("Stepper ");
        Serial.print(motorNum);
        Serial.print(" is at = ");
        Serial.print(convertStepperPosToDeg(motorNum-1, steppers[motorNum-1]->currentPosition()));
        Serial.print(" deg [");
        Serial.print(steppers[motorNum-1]->currentPosition());
        Serial.println(" steps]");
    }
    else
    {
        Serial.println("Invalid number of parameters");
    }
}

void setMotorSpeed()
{
    if (numTokens == 3)
    {
        long motorNum;
        if (!isValidMotorNum(incomingParams[1], motorNum))
        {
            return;
        }

        double targetSpeed;
        if (!isValidMotorSpeed(incomingParams[2], motorNum, targetSpeed))
        {
            return;
        }
        steppers[motorNum-1]->stop();
        steppers[motorNum-1]->disableOutputs();
        steppers[motorNum-1]->setSpeed(targetSpeed);
        steppers[motorNum-1]->setMaxSpeed(targetSpeed);
        steppers[motorNum-1]->enableOutputs();
        if (VERBOSE)
        {
            Serial.print("Stepper ");
            Serial.print(motorNum);
            Serial.print(" speed has been set to ");
            Serial.println(targetSpeed);
        }
    }
    else
    {
        Serial.println("Invalid number of parameters");
    }
}

void setMotorAcceleration()
{
    if (numTokens == 3)
    {
        long motorNum;
        if (!isValidMotorNum(incomingParams[1], motorNum))
        {
            return;
        }

        double targetAcceleration;
        if (!isValidMotorAcceleration(incomingParams[2], motorNum, targetAcceleration))
        {
            return;
        }
        steppers[motorNum-1]->stop();
        steppers[motorNum-1]->disableOutputs();
        steppers[motorNum-1]->setAcceleration(targetAcceleration);
        steppers[motorNum-1]->enableOutputs();
        if (VERBOSE)
        {
            Serial.print("Stepper ");
            Serial.print(motorNum);
            Serial.print(" acceleration has been set to ");
            Serial.println(targetAcceleration);
        }
    }
    else
    {
        Serial.println("Invalid number of parameters");
    }
}

bool isValidMotorNum(char* str, long& num)
{
    char* endptr;
    num = strtol(str, &endptr, 10);
    if (endptr == str || *endptr != '\0')
    {
        Serial.print("Parameter ");
        Serial.print(str);
        Serial.println(" is not an integer");
        return false;
    }
    else
    {
        if (num <= 0 || num > numSteppers)
        {
            Serial.println("Stepper number is invalid or out of bounds");
            return false;
        }
        else
        {
            return true;
        }
    }
}

bool isValidMotorAcceleration(char* str, long motorNum, double& val)
{
    char* endptr;
    val = strtod(str, &endptr);
    if (endptr == str || *endptr != '\0')
    {
        Serial.print("Parameter ");
        Serial.print(incomingParams[2]);
        Serial.println(" is not a number");
        return false;
    }
    else
    {
        if (val < 0 || val > maxMotorAcceleration[motorNum-1])
        {
            Serial.print("Acceleration ");
            Serial.print(val);
            Serial.println(" is out of range");
            return false;
        }
        else
        {
          return true;
        }
    }
}

bool isValidMotorSpeed(char* str, long motorNum, double& val)
{
    char* endptr;
    val = strtod(str, &endptr);
    if (endptr == str || *endptr != '\0')
    {
        Serial.print("Parameter ");
        Serial.print(incomingParams[2]);
        Serial.println(" is not a number");
        return false;
    }
    else
    {
        if (val < 0 || val > maxMotorSpeed[motorNum-1])
        {
            Serial.print("Speed ");
            Serial.print(val);
            Serial.println(" is out of range");
            return false;
        }
        else
        {
          return true;
        }
    }
}

bool isValidTargetPos(char* str, long motorNum, double& pos)
{
    char* endptr;
    pos = strtod(str, &endptr);
    if (endptr == str || *endptr != '\0')
    {
        Serial.print("Parameter ");
        Serial.print(incomingParams[2]);
        Serial.println(" is not a number");
        return false;
    }
    else
    {
        int min_limit = convertStepperPosToDeg(motorNum-1, minPosition[motorNum-1]);
        int max_limit = convertStepperPosToDeg(motorNum-1, maxPosition[motorNum-1]);
        if (pos < min_limit || pos > max_limit)
        {
            Serial.print("Position ");
            Serial.print(pos);
            Serial.print(" is out of range. Limit for joint is [");
            Serial.print(min_limit);
            Serial.print(" ");
            Serial.print(max_limit);
            Serial.println("]");
            return false;
        }
        else
        {
          return true;
        }
    }
}
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

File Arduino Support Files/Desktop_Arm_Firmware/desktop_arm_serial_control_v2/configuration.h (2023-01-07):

/*
* Configuration.h
*
* Basic settings for defining hardware, configuring the SerLCD, endstops, and features
*
*/

#pragma once

// Show custom "Desktop Arm" bootscreen on setup. Uncommend to enable
//#define SHOW_BOOTSCREEN

// Choose the name from boards.h that matches your setup
#ifndef MOTHERBOARD
  #define MOTHERBOARD BOARD_RAMPS_14_EFB
#endif

/**
 * Select the serial port on the board to use for communication with the host.
 * This allows the connection of wireless adapters (for instance) to non-default port pins.
 * Serial port -1 is the USB emulated serial port, if available.
 * Note: The first serial port (-1 or 0) will always be used by the Arduino bootloader.
 *
 * :[-1, 0, 1, 2, 3, 4, 5, 6, 7]
 */
#define SERIAL_PORT 0

/**
 * Serial Port Baud Rate
 * This is the default communication speed for all serial ports.
 * Set the baud rate defaults for additional serial ports below.
 *
 * 250000 works in most cases, but you might try a lower speed if
 * you commonly experience drop-outs during host printing.
 * You may try up to 1000000 to speed up SD file transfer.
 *
 * :[2400, 9600, 19200, 38400, 57600, 115200, 250000, 500000, 1000000]
 */
#define BAUDRATE 115200
#define CONNECT_LED_PIN_OUT 16 // Also AUX4_18_PIN on pin config

//===========================================================================
//============================= PID Settings ================================
//===========================================================================
// PID Tuning Guide here: https://reprap.org/wiki/PID_Tuning
#define USE_PID false // Set to true to use PID tuning for joint positons
#define Kp  22.20
#define Ki   1.08
#define Kd 114.00
//#define PID_K1 0.95      // Smoothing factor within any PID loop

// Define endstops that the robot will use here. Usually want to use at least one per joint to 
// protect the robot from collisions. 
//
// The last joint (5) is assumed to be a servo right now and should know its relative position. 
#define USE_JOINT0_PLUG
#define USE_JOINT1_PLUG
#define USE_JOINT2_PLUG
#define USE_JOINT3_PLUG
#define USE_JOINT4_PLUG
#define USE_JOINT5_PLUG


/* Fan Control */
#define ENABLE_FAN true
/**
 * Stepper Drivers
 *
 * These settings allow Marlin to tune stepper driver timing and enable advanced options for
 * stepper drivers that support them. You may also override timing options in Configuration_adv.h.
 *
 * A4988 is assumed for unspecified drivers.
 *
 * Use TMC2208/TMC2208_STANDALONE for TMC2225 drivers and TMC2209/TMC2209_STANDALONE for TMC2226 drivers.
 *
 * Options: A4988, A5984, DRV8825, LV8729, L6470, L6474, POWERSTEP01,
 *          TB6560, TB6600, TMC2100,
 *          TMC2130, TMC2130_STANDALONE, TMC2160, TMC2160_STANDALONE,
 *          TMC2208, TMC2208_STANDALONE, TMC2209, TMC2209_STANDALONE,
 *          TMC26X,  TMC26X_STANDALONE,  TMC2660, TMC2660_STANDALONE,
 *          TMC5130, TMC5130_STANDALONE, TMC5160, TMC5160_STANDALONE
 * :['A4988', 'A5984', 'DRV8825', 'LV8729', 'L6470', 'L6474', 'POWERSTEP01', 'TB6560', 'TB6600', 'TMC2100', 'TMC2130', 'TMC2130_STANDALONE', 'TMC2160', 'TMC2160_STANDALONE', 'TMC2208', 'TMC2208_STANDALONE', 'TMC2209', 'TMC2209_STANDALONE', 'TMC26X', 'TMC26X_STANDALONE', 'TMC2660', 'TMC2660_STANDALONE', 'TMC5130', 'TMC5130_STANDALONE', 'TMC5160', 'TMC5160_STANDALONE']
 */
#define JOINT0_DRIVER_TYPE  TMC2208 // For base
#define JOINT1_DRIVER_TYPE  TMC2208 // For both shoulder stepper motors
#define JOINT2_DRIVER_TYPE  TMC2208 // For elbow
#define JOINT3_DRIVER_TYPE  TMC2208 // For wrist roll
#define JOINT4_DRIVER_TYPE  TMC2208 // For wrist bend

#define HAS_TMC_UART false
#define HAS_WIRED_LCD false

#define motorInterfaceType 1

// =====================================================================
// ====================== Movement Settings ============================
// =====================================================================

// Travel limits (mm) after homing, corresponding to endstop positions.
#define JOINT0_MIN_POS 0
#define JOINT1_MIN_POS 0
#define JOINT2_MIN_POS 0
#define JOINT3_MIN_POS 0
#define JOINT4_MIN_POS 0
#define JOINT0_MAX_POS 14000
#define JOINT1_MAX_POS 10000
#define JOINT2_MAX_POS 3000
#define JOINT3_MAX_POS 2000
#define JOINT4_MAX_POS 4000

// Define the speed and acceleration limits for each joint in steps per revolution
#define JOINT0_MAX_SPEED 40000
#define JOINT1_MAX_SPEED 40000
#define JOINT2_MAX_SPEED 40000
#define JOINT3_MAX_SPEED 40000
#define JOINT4_MAX_SPEED 40000
#define JOINT0_MAX_ACCELERATION 40000
#define JOINT1_MAX_ACCELERATION 40000
#define JOINT2_MAX_ACCELERATION 40000
#define JOINT3_MAX_ACCELERATION 40000
#define JOINT4_MAX_ACCELERATION 40000

// Define the homing buffer for each joint (how much to move forward after triggering homing/limit switch)
#define JOINT0_HOMING_BUFFER 5.0 // units: deg. 
#define JOINT1_HOMING_BUFFER 5.0
#define JOINT2_HOMING_BUFFER 5.0
#define JOINT3_HOMING_BUFFER 5.0
#define JOINT4_HOMING_BUFFER 5.0
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

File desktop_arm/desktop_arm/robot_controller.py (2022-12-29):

#!/usr/bin/env python3
"""
Copyright 2022 Jonathan Shulgach

This Source Code Form is subject to the terms of the Mozilla Public
License, v. 2.0. If a copy of the MPL was not distributed with this
file, You can obtain one at https://mozilla.org/MPL/2.0/.

Contact: Jonathan Shulgach (jonathan@shulgach.com)

'robot_controller.py' handles the main task of starting the moveit_servo server and handling movement commands coming in and converting them into robot movements. 

"""

# ROS libraries
import rclpy
from rclpy.parameter import Parameter
from rclpy.node import Node
from std_srvs.srv import Trigger
from std_msgs.msg import String, Int32
from geometry_msgs.msg import TwistStamped
from control_msgs.msg import JointJog
from moveit_msgs.msg import PlanningScene

# robot drivers
from desktop_arm.arm_drivers import *


class ControllerToRobot(Node):
    def __init__(self, node_name='desktop_arm_controller_node', rate=10, verbose=False):
        """This is the object that handles controller inputs and directs them to topics understood
        by the Servo Server for twist and joint changes. 
        
        Parameters:
        -----------
        node_name : str
            Specific name for ROS2 Node
        rate : int
            Publishing rate for running update commands
        verbose : bool
            Enable/disable verbose output for debugging on the terminal 
        
        """    
        super().__init__(node_name,
                         allow_undeclared_parameters=False,
                         automatically_declare_parameters_from_overrides=False
                         )
        self.rate = rate
        self.verbose = verbose
        
        # Potential update, want to get current joint state
        self.current_joint_state = [0.0, 0.0, 0.0, 0.0, 0.0, 0.0]
        self.previous_joint_state = [0.0, 0.0, 0.0, 0.0, 0.0, 0.0]
        self.desired_joint_state = [0.0, 0.0, 0.0, 0.0, 0.0, 0.0]
        #self.robot_state_type = robotStateTypes["joint_state"]
                
        # declare ROS2 params, create publishers, subscribers, and timer
        self.init_ros_params()
        self.init_pub_sub()
        self.create_timer(1/self.rate, self.timer_callback) # frequency rate of running commands
        self.robot_state_type = robotStateTypes[self.get_parameter("robot_cmd_type").value]
        self.logger("Robot message operation type: {}".format(self.get_parameter("robot_cmd_type").value))
        
        # Create controller object, assume XBOX controller        
        self.user_controller = XboxController(self, self.robot_state_type)
        #self.user_controller = KeyboardController(self, self.robot_state_type)


        
        # Start servo service client
        #self.create_servo_client()
        self.logger("Robot Controller node created!")
        
        
    def init_ros_params(self):
        """ Declare all ros2 params
        """
        self.declare_parameter("base_frame_ID","base_link")      
        self.declare_parameter("eef_frame_ID","tool0")
        self.declare_parameter("controller_type","xbox")
        self.declare_parameter("robot_cmd_type","joint_state")
        self.declare_parameter("joint_step", 1.0) # in degrees
        self.declare_parameter("publishing_rate", 1.0) # safe, once every second
        self.declare_parameter("controller_joint_names", None)
        #self.robot_state_type = robotStateTypes["joint_state"] # Will change to parameter passed

        #self.joint_names = self.get_parameter("controller_joint_names").value
        #if self.joint_names is not None:
        #    for joint in self.joint_names:
        #        self.declare_patameter(joint+".min_lim")
        #        self.declare_patameter(joint+".max_lim")
        #else:
        #    self.logger('Warning: Joint names not found or sisue with loading. Joint state publishing disabled')
        
         
        self.eef_frame_ID = self.get_parameter("eef_frame_ID").value
        self.base_frame_ID = self.get_parameter("base_frame_ID").value
        self.controller_type = self.get_parameter("controller_type").value
        self.joint_step = self.get_parameter("joint_step").value
        self.frame_to_publish = self.base_frame_ID


    def init_pub_sub(self):
        """ Set up all publishers and subscribers with configured topics.
        """
        #self.twist_pub = self.create_publisher(TwistStamped, "/servo_server/delta_twist_cmds", 10) # Once the kinematics urdf file is fixed these will be enables
        #self.joint_pub = self.create_publisher(JointJog, "/servo_server/delta_joint_cmds", 10)
        #self.joint_pub = self.create_publisher(JointState, "/joint_states", 10)

        # The controller type will take care of publishers and subscribers for robot specific commands, but we need
        # the planning scene and chatter debugging topic
        self.collision_pub = self.create_publisher(PlanningScene, "/planning_scene", 10)
        self.chatter_pub = self.create_publisher(String, "chatter", 10)
        #self.gripper_pub = self.create_publisher(Int32, "gripper_state", 1)
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

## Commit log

2020-04-05 Add files via upload
    ROS package for controlling arm through ROSserial and teleop joystick
2020-04-05 Add files via upload
    Now controlling all servos
2020-04-26 Updated Arduino firmware includes LED state
2020-04-26 Add files via upload
    New joystick threshold crossing for moving servos
2020-04-28 updated firmware, using arduino pro mini
2021-09-17 robot arm solidworks model parts!
    [Arm 01.SLDPRT, Arm 01_r1.SLDPRT, Arm 02 v2.SLDPRT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]
2021-09-17 urdf exporter links
2021-09-18 definitely need servo_server namespace otherwise the robot server wont get new values
2022-05-16 Lots of models added from submodule for moveo arm
    [2.54 mm DUPONT MALE PIN HEADER, IO, 2X20, RPi4ModelB.SLDPRT, 2.54 mm DUPONT MALE PIN HEADER, IO, 2X40, RPi4ModelB.SLDPRT, 2.54 mm DUPONT MALE PIN HEADER, POE, 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]
2022-05-16 desktop arm assembly current model, removed unused models
    [S-120-12 PSU.SLDASM, S-120-12 PSU.SLDPRT]
2022-05-21 Better model of arm for urdf
2022-05-21 URDF files created!
    [base_link.STL, desktop_arm_base.SLDPRT, desktop_arm_description.csv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]
2022-06-06 Newest sketches with working steppers! (remember enable pins)
    [configuration.h]
2022-09-27 New front page photo!
    [Rotating Base.SLDPRT, Rotating Base.STL]
2022-10-02 Cleaning old files and updated control firmware
    [configuration.h]
2022-10-03 added rviz feature, cleaned up controller code
    [desktop-arm.ros2_control.xacro, desktop-arm.urdf.xacro, desktop-arm_ros_controllers.yaml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]
2022-10-14 joint state publishing, right now just the first joint
    [desktop_arm.urdf, desktop_arm_broken.urdf]
2022-10-15 joint state commands now get published, arduino driver needs to be tested
    [joint_limits.yaml]
2022-12-18 Touchups to readme and installation files to support ROS2 Humble
    - Install Ubuntu 22.04, not 22.10, need to make sure.
    - If the nodes are on the network then it's possible to control the robot from another computer. Wireless method will not work though
    [arduino_driver.py, arm_drivers.py, robot_controller.py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]
2022-12-29 Supports remote control with the gripper at least
2023-01-01 Brand new command parser/system controller
    For some reason the switch/case structure just stopped working on all of my Arduinos and I spent a couple hours looking for a problem which had no origin...
    This was a great excuse to completely overhaul the command parsing system, and a "few other things"
    The new serial control firmware (version 2) with `desktop_arm_serial_control_v2` now has a bunch of features:
    - It uses a character array to read the entire incoming message instead of reading each byte as the command gets parsed
    - tokens for command messages with multiple parts, with a configurable delimiter (currently set to " ")
    - All stepper motor hardware parameters have been moved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
    [configuration.h]
2023-01-02 fan control
    [configuration.h]
2023-01-02 new gripper and motor commands
2023-01-07 Now accepts degree values instead of stepper motor positions.
    Zero command will send joint to its zero position (halfway between minimum and maximum rotation limits in degrees)
    [configuration.h]
2023-01-11 fixes to links for arduino mega and ramps board

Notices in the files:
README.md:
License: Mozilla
